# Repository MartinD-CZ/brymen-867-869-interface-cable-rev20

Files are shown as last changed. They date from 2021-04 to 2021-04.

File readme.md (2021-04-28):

# Brymen 867/869 adapter cable rev2.0
*see the article [here](http://embedblog.eu/?p=475) or the listing [here](https://www.tindie.com/products/martind/brymen-867869-adapter-cable/)*

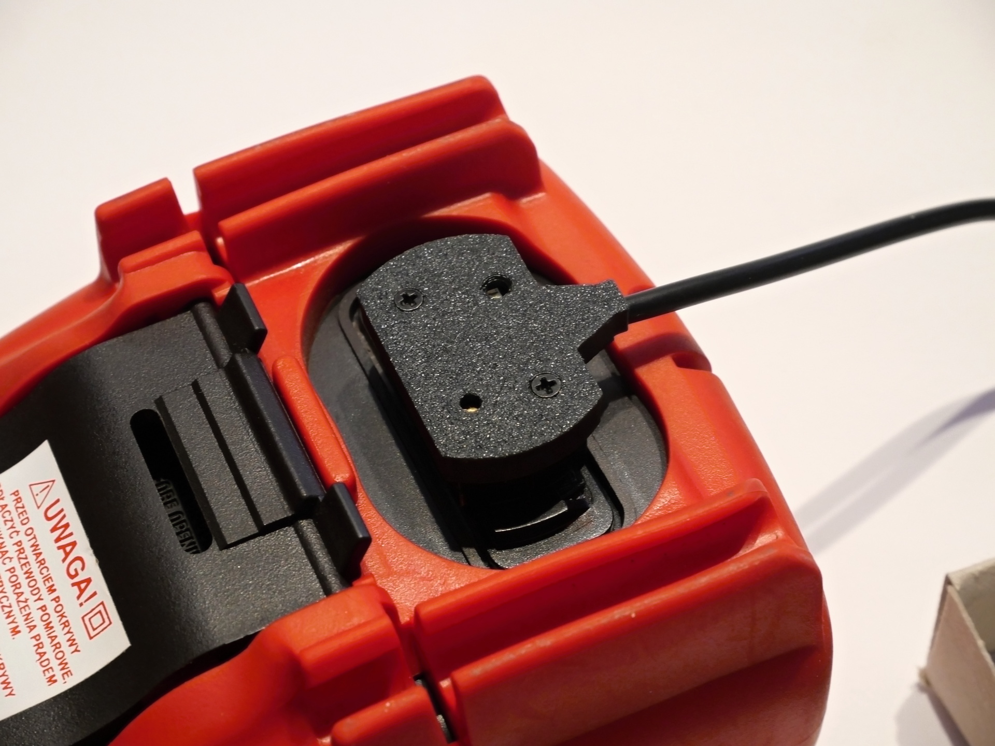
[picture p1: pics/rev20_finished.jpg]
A picture of the finished device


## Features
- reads data from Brymen 867/869 via infrared
- sends the measurements at 115200 baud via serial port
- output data rate and format adjustable (5 readings/s, 1 reading/s, single reading); settings are stored in EEPROM and remembered on next power up
- BOOT0 pin available as a button, so you can update the FW without disassembling the case
- activity LED

*Here's how the serial output looks:*
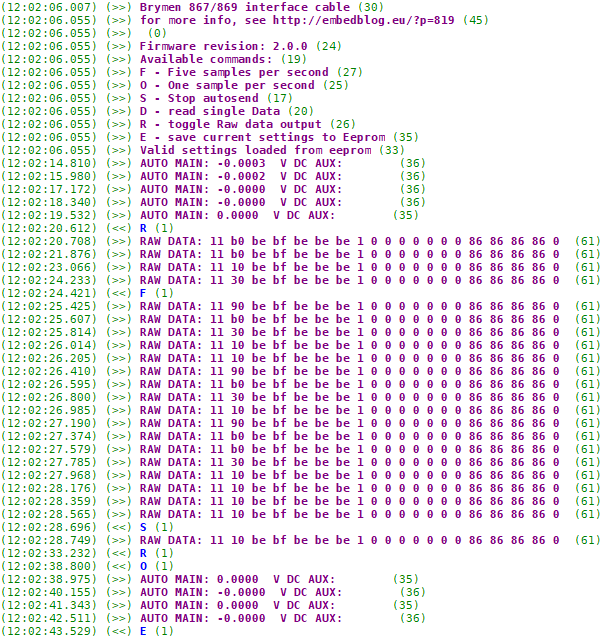
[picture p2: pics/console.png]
Console output


*If you are ordering it without the USB cable, here's how to connect it:*
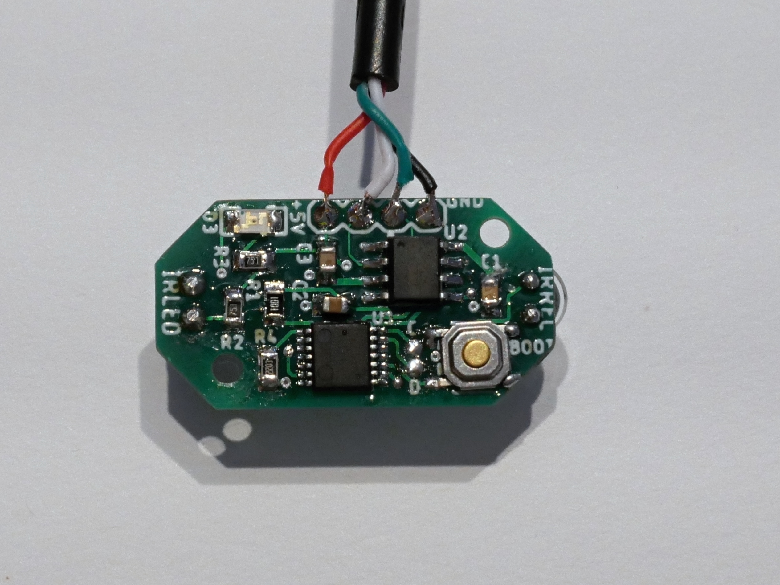
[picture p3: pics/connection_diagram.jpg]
Connection diagram


*Note: previous revisions (1.x) can be found [here](https://github.com/MartinD-CZ/brymen-867-interface-cable/blob/master/README.md)*

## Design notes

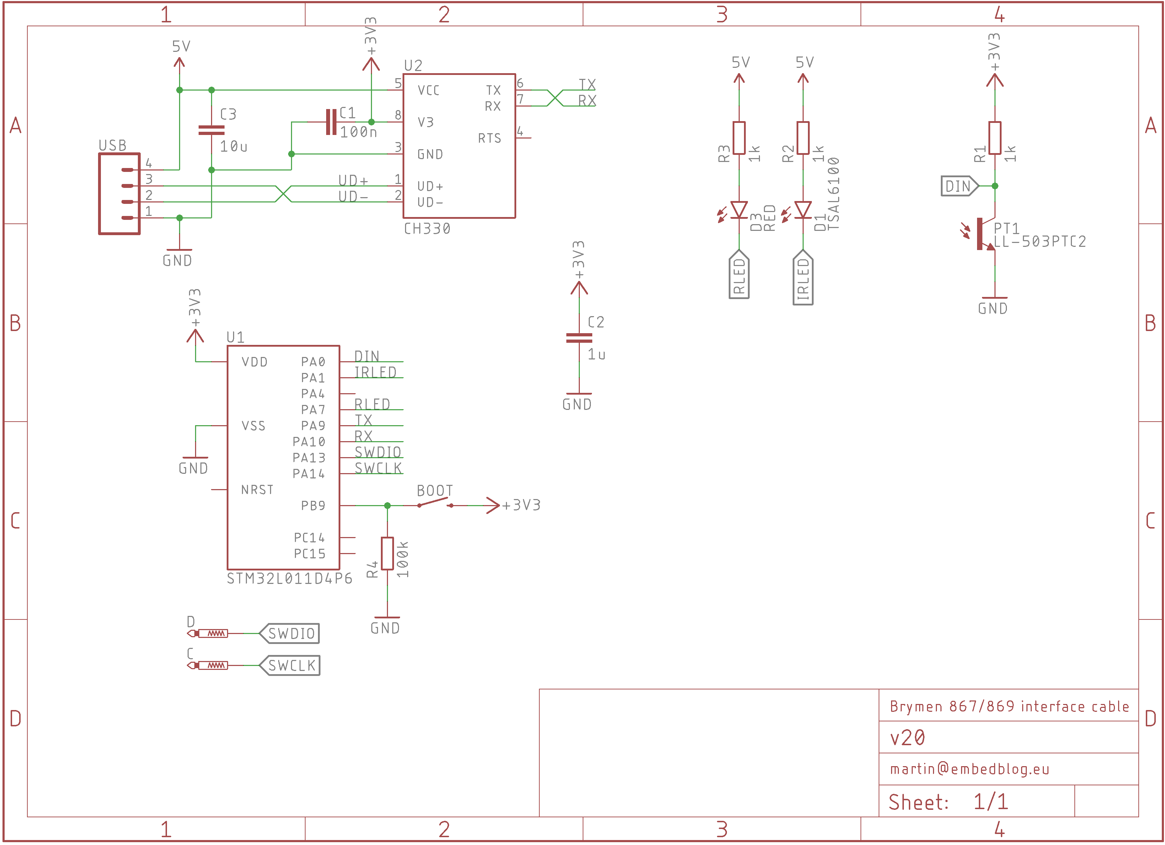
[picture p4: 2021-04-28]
pcbs/v20.png

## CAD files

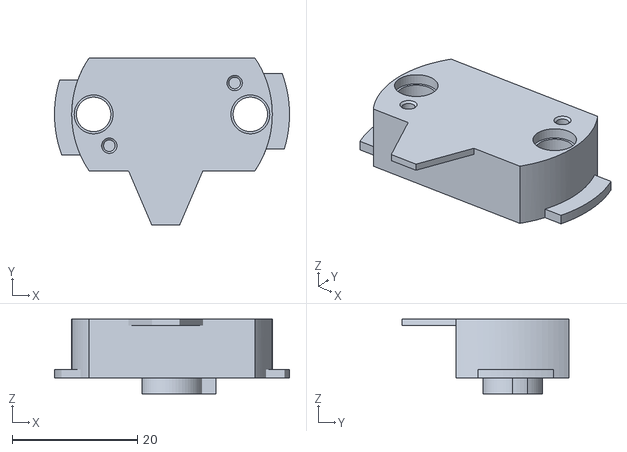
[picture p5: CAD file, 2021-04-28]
case/bottom.stl
37.5 x 26.6 x 11.9

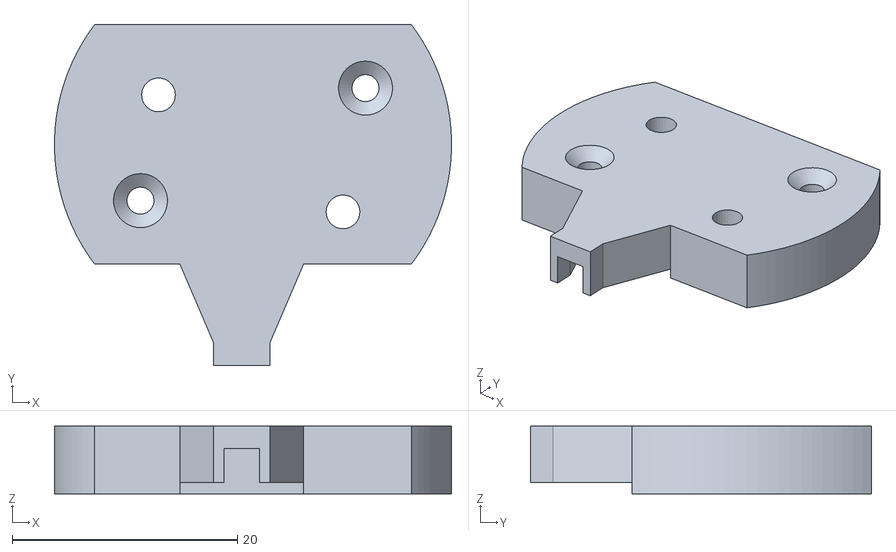
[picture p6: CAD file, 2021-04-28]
case/top.stl
35.3 x 30.3 x 6.00

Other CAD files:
case/case.f3d

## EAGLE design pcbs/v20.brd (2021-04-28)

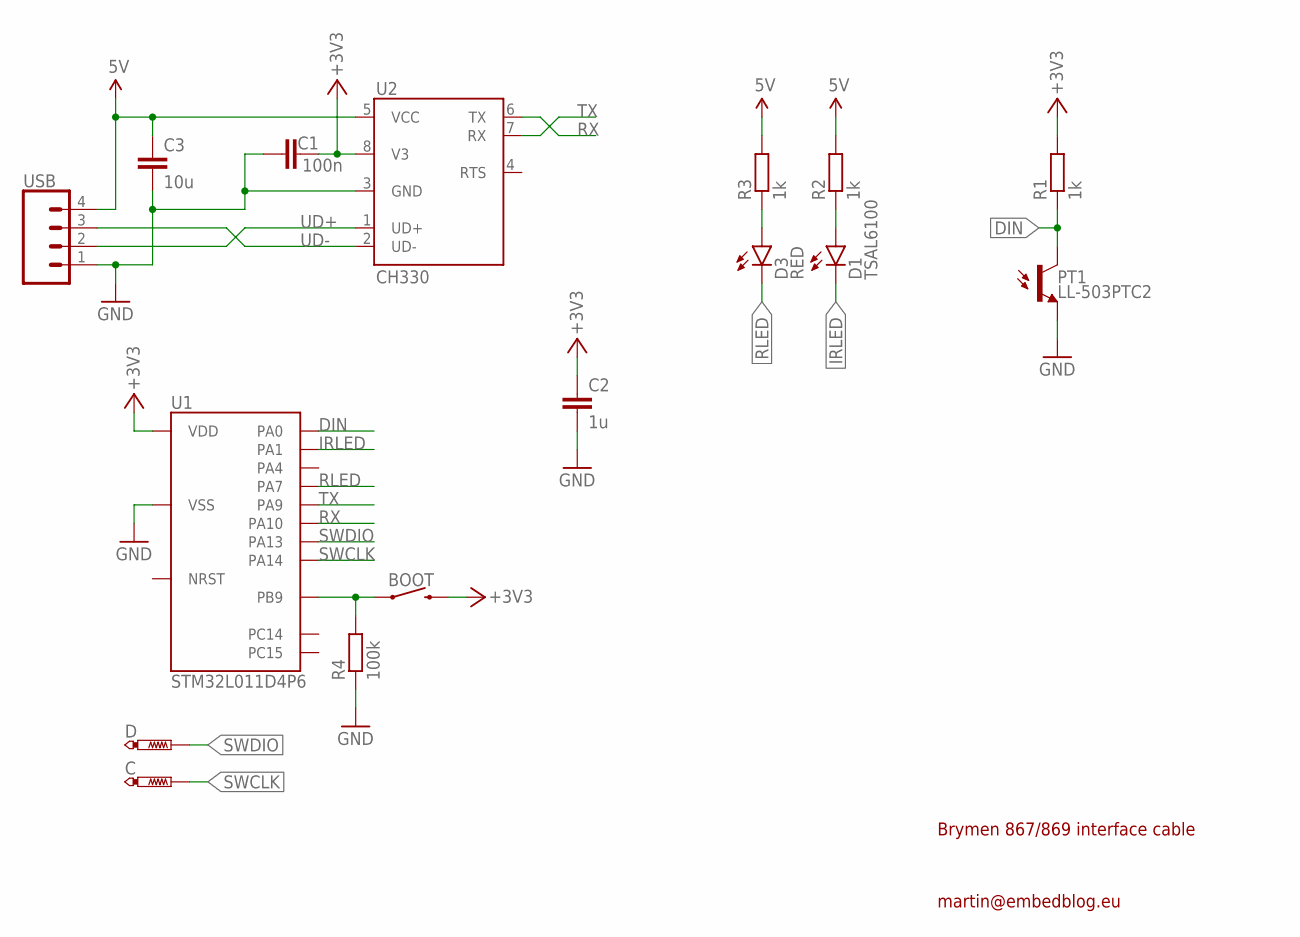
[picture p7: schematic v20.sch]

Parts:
BOOT: MOMENTARY-SWITCH-SPST-SMD-5.2MM; TACTILE_SWITCH_SMD_5.2MM
C: PTR1B1,27; B1,27
C1: 100n; C0805
C2: 1u; C0805
C3: 10u; C0805
D: PTR1B1,27; B1,27
D1: TSAL6100; LED5MM
D3: RED; LED-1206
PT1: LL-503PTC2; LED5MM
R1, R2, R3: 1k; R0805
R4: 100k; R0805
U1: STM32L011D4P6; TSSOP14
U2: CH330; SO08
USB: CONN_04; 1X04

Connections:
5V: C3.1, R2.2, R3.2, U2.5 (VCC), USB.4
+3V3: BOOT.3 (2), C1.2, C2.1, R1.2, U1.10 (VDD), U2.8 (V3)
DIN: PT1.K (C), R1.1, U1.5 (PA0)
GND: C1.1, C2.2, C3.2, PT1.A (E), R4.1, U1.9 (VSS), U2.3 (GND), USB.1
IRLED: D1.K (C), U1.6 (PA1)
unnamed: BOOT.1, R4.2, U1.1 (PB9)
unnamed: D1.A, R2.1
unnamed: D3.A, R3.1
RLED: D3.C, U1.8 (PA7)
RX: U1.12 (PA10), U2.6 (TX)
SWCLK: C.TP, U1.14 (PA14)
SWDIO: D.TP, U1.13 (PA13)
TX: U1.11 (PA9), U2.7 (RX)
UD+: U2.1 (UD+), USB.2
UD-: U2.2 (UD-), USB.3

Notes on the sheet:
Brymen 867/869 interface cable
martin@embedblog.eu

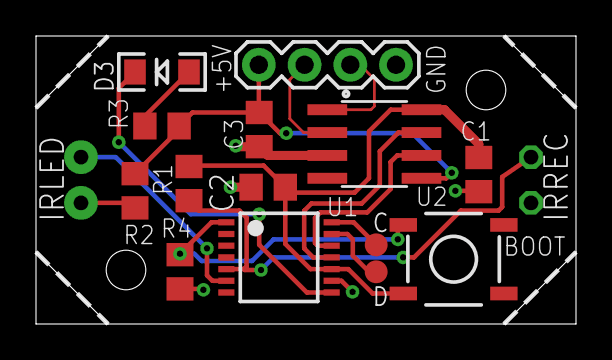
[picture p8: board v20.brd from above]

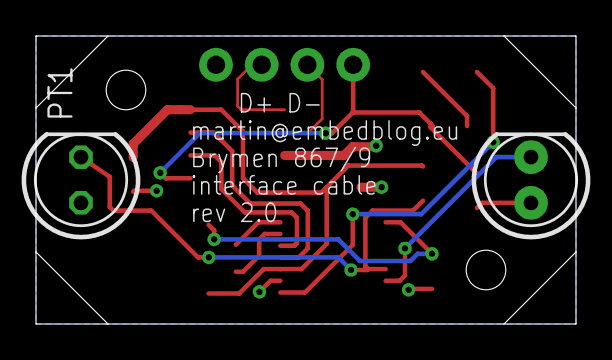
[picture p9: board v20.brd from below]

Board: 2 copper layers, 30.0 x 16.0 mm, 16 parts (2 on the bottom side), 15 nets.

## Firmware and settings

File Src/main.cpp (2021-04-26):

#include "libCORE.h"
#include "libGPIO.h"
#include "libUART.h"
#include "libNVM.h"
#include "libTIM.h"

#include "version.h"
#include "decoder.h"

gpio led_red{GPIOA, 7};
gpio led_ir{GPIOA, 1};
gpio phototransistor{GPIOA, 0};

uart_irq com{USART2};

timer_basic timer_us{TIM2};			//timer for microsend delay generation

volatile mode_t mode;
volatile bool rawDataEnabled;

char com_txBuffer[128];
char com_rxBuffer[4];

void comIdleLineCB(void);

//TODO: set baud rate

int main(void)
{
	rcc::initHSI();
	rcc::initSystemClock(rcc::vRange::high, rcc::sysclk::HSI);
	rcc::disableMSI();

	led_red.initOutput(gpio::speed::low, gpio::output::high, gpio::type::opendrain);
	led_ir.initOutput(gpio::speed::low, gpio::output::high, gpio::type::opendrain);
	phototransistor.initInput();

	com.init(115200);
	com.enableTX(gpio{GPIOA, 9, gpio::af::_4}, com_txBuffer, sizeof(com_txBuffer));
	com.enableRX(gpio{GPIOA, 10, gpio::af::_4}, com_rxBuffer, sizeof(com_rxBuffer));
	com.enableIdleLine(comIdleLineCB);
	NVIC_EnableIRQ(USART2_IRQn);

	timer_us.init(16, 0xFFFF);
	timer_us.start();

	//print initial info on the serial port
	com.print("\n\nBrymen 867/869 interface cable\nfor more info, see http://embedblog.eu/?p=819\n\n");
	com.printf("Firmware revision: %s\n", _V_BUILD_TAG);
	com.print("Available commands:\n");
	com.print("F - Five samples per second\n");
	com.print("O - One sample per second\n");
	com.print("S - Stop autosend\n");
	com.print("D - read single Data\n");
	com.print("R - toggle Raw data output\n");
	com.print("E - save current settings to Eeprom\n");

	eeprom::enableClock();
	uint8_t data[2];
	eeprom::read(0, data, sizeof(data));
	if (data[0] == EEPROM_VALID_FLAG)
	{
		rawDataEnabled = data[1] >> 7;
		mode = (mode_t)(data[1] & 0b111);
		com.print("Valid settings loaded from eeprom\n");
	}

	//startup blink
	for (uint8_t i = 0; i < 6; i++)
	{
		led_red.toggle();
		tick::delay(250);
	}

	while (1)
	{
		if (receiveMessage())
		{
			led_red = LOW;
			processMessage();
			tick::delay(50);
			led_red = HIGH;

			if (mode == mode_t::sendRate1Hz) tick::delay(920);
			else if (mode == mode_t::sendRate5Hz) continue;
			else
			{
				mode = mode_t::stop;
				while (mode == mode_t::stop);
			}
		}
	}
}

void comIdleLineCB(void)
{
	switch(com_rxBuffer[0])
	{
		case 'F': mode = mode_t::sendRate5Hz; break;
		case 'O': mode = mode_t::sendRate1Hz; break;
		case 'S': mode = mode_t::stop; break;
		case 'D': mode = mode_t::sendSingleSample; break;
		case 'R': rawDataEnabled = !rawDataEnabled; break;
		case 'E':
			uint8_t data[2] = {EEPROM_VALID_FLAG, (uint8_t)((uint8_t)mode | ((uint8_t)rawDataEnabled << 7))};
			eeprom::write(0, data, sizeof(data));
			break;
	}

	com.rxReset();
}

extern "C" void USART2_IRQHandler(void)
{
	com.IRQHandler();
}

void custom_assert(const char* file, uint32_t line)
{
	com.printf("ERROR! Assert failed: file %s, line %d", file, line);
	while (com.txCharsRemaining());
	#ifdef DEBUG
	__asm("bkpt 0");
	#endif
}

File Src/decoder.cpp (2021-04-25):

#include "libCORE.h"
#include "libUART.h"
#include "libTIM.h"

#include "stdlib.h"

#include "decoder.h"

extern uart_irq com;
extern gpio led_ir;
extern gpio phototransistor;

extern timer_basic timer_us;

uint8_t data[20];
extern volatile bool rawDataEnabled;

void delay_us(uint16_t us)
{
	timer_us.setCounter(0);
	while (timer_us.getCounter() < us);
}

uint8_t receiveByte(void)
{
	uint8_t temp = 0;

	for (uint8_t i = 0; i < 8; i ++)
	{
		led_ir = LOW;
		delay_us(CLOCK_DELAY_US);
		led_ir = HIGH;

		/*if (phototransistor == HIGH) temp |= (1 << i);
		delay_us(CLOCK_DELAY_US);*/

		delay_us(CLOCK_DELAY_US / 2);
		if (phototransistor == HIGH) temp |= (1 << i);
		delay_us(CLOCK_DELAY_US / 2);
	}

	return temp;
}

bool receiveMessage(void)
{
	led_ir = LOW;
	tick::delay(10);
	led_ir = HIGH;

	uint32_t start = tick::get();
	while (phototransistor == HIGH)
	{
		if (tick::get() - start > 500) return false;
	}

	for (uint8_t i = 0; i < 20; i ++) data[i] = receiveByte();

	return 1;
}

void processMessage(void)
{
	if (rawDataEnabled)
	{
		com.print("RAW DATA: ");

		for (uint8_t i = 0; i < 20; i++)
		{
			char buffer[8];
			itoa(data[i], buffer, 16);
			com.print(buffer);
			com.print(" ");
		}

		com.print("\n");
		return;
	}

	//decode the output
	if (data[0] & 0x01)
		com.print("AUTO ");
	if ((data[0] >> 7) & 0x01)
		com.print("AVG ");
	if ((data[0] >> 6) & 0x01)
		com.print("MIN ");
	if ((data[0] >> 5) & 0x01)
		com.print("MAX ");
	if ((data[0] >> 2) & 0x01)
		com.print("CREST ");
	if ((data[0] >> 1) & 0x01)
		com.print("REC ");
	if ((data[0] >> 3) & 0x01)
		com.print("HOLD ");
	if (data[2] & 0x01)
		com.print("DELTA ");
	if (data[9] & 0x01)
		com.print("BEEP ");

	//DECODE MAIN DISPLAY
	com.print("MAIN: ");

	if ((data[1] >> 7) & 0x01)
		com.print("-");

	for (uint8_t i = 0; i < 6; i++)
	{
		char temp[] = {(char)(48 + decodeDigit(data[2 + i])), '\0'};
		com.print(temp);
		if ((data[3 + i] & 0x01) & (i < 4))
			com.print(".");
	}
	com.print(" ");

	//DECODE UNIT PREFIX FOR MAIN DISPLAY
	if ((data[13] >> 6) & 0x01)
		com.print("n");
	if ((data[14] >> 3) & 0x01)
		com.print("u");
	if ((data[14] >> 2) & 0x01)
		com.print("m");
	if ((data[14] >> 6) & 0x01)
		com.print("k");
	if ((data[14] >> 5) & 0x01)
		com.print("M");

	//DECODE UNIT FOR MAIN DISPLAY
	if (data[7] & 0x01)
		com.print("V");
	if ((data[13] >> 7) & 0x01)
		com.print("A");
	if ((data[13] >> 5) & 0x01)
		com.print("F");
	if ((data[13] >> 4) & 0x01)
		com.print("S");
	if ((data[14] >> 7) & 0x01)
		com.print("D%");
	if ((data[14] >> 4) & 0x01)
		com.print("Ohm");
	if ((data[14] >> 1) & 0x01)
		com.print("dB");
	if (data[14] & 0x01)
		com.print("Hz");
	com.print(" ");

	//DC OR AC
	if ((data[0] >> 4) & 0x01)
		com.print("DC ");
	if (data[1] & 0x01)
		com.print("AC ");

	//DECODE AUXILIARY DISPLAY
	com.print("AUX: ");

	if ((data[8] >> 4) & 0x01)
		com.print("-");

	for (uint8_t i = 0; i < 4; i++)
	{
		char temp[] = {(char)(48 + decodeDigit(data[9 + i])), '\0'};
		com.print(temp);
		if ((data[10 + i] & 0x01) & (i < 3))
			com.print(".");
	}

	com.print(" ");

	//DECODE UNIT PREFIX FOR AUXILIARY DISPLAY
	if ((data[8] >> 1) & 0x01)
		com.print("m");
	if (data[8] & 0x01)
		com.print("u");
	if ((data[13] >> 1) & 0x01)
		com.print("k");
	if (data[13] & 0x01)
		com.print("M");

	//DECODE UNIT FOR AUXILIARY DISPLAY
	if ((data[13] >> 2) & 0x01)
		com.print("Hz");
	if ((data[13] >> 3) & 0x01)
		com.print("V");
	if ((data[8] >> 2) & 0x01)
		com.print("A");
	if ((data[8] >> 3) & 0x01)
		com.print("%4-20mA");

	com.print(" ");
	if ((data[13] >> 2) & 0x01)
		com.print("AC");

	//FINISH
	com.print("\n");

	//detect low battery
	if ((data[8] >> 7) & 0x01)
		com.print(" LOW BAT\n");
}

int8_t decodeDigit(uint8_t source)
{
	int8_t result = 0;

	switch (source >> 1)
	{
		case 0b1011111: result = 0; break;
		case 0b1010000: result = 1; break;
		case 0b1101101: result = 2; break;
		case 0b1111100: result = 3; break;
		case 0b1110010: result = 4; break;
		case 0b0111110: result = 5; break;
		case 0b0111111: result = 6; break;
		case 0b1010100: result = 7; break;
		case 0b1111111: result = 8; break;
		case 0b1111110: result = 9; break;
		case 0b1111001: result = ('d' - 48); break;
		case 0b0010000: result = ('i' - 48); break;
		case 0b0111001: result = ('o' - 48); break;
		case 0b0001011: result = ('L' - 48); break;
		case 0b0000000: result = (' ' - 48); break;
		default: result = ('?' - 48); break;
	}

	return result;
}

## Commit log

2021-04-25 added uart command decoding
2021-04-26 switched off automatic gitgnore modification
2021-04-28 added readme, case files, pictures
    [bottom.stl, case.f3d, top.stl]
2021-04-28 added PCB files
    [v20.brd, v20.sch]

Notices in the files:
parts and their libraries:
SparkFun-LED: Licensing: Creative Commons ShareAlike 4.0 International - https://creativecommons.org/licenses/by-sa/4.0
